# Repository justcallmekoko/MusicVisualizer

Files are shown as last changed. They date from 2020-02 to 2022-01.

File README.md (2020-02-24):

# Music Visualizer
<p align="center">
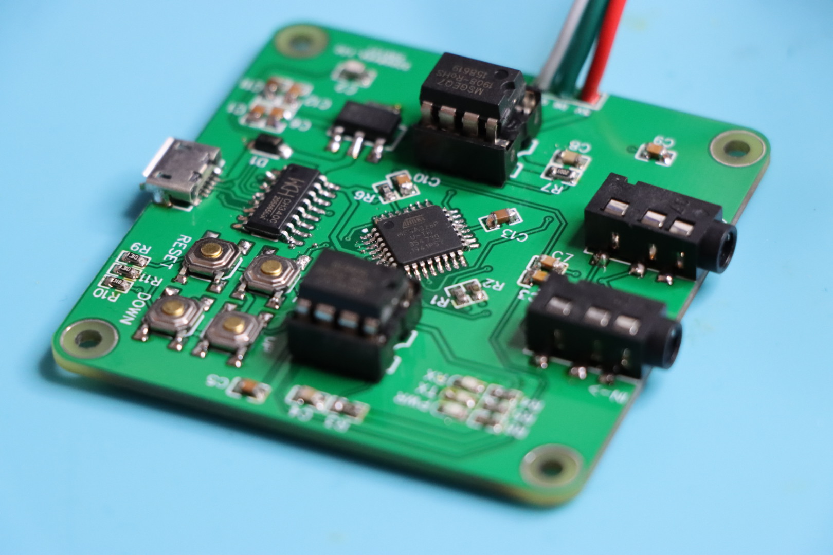
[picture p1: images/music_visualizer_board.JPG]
  
  
  <br>
  <a href="https://www.instagram.com/just.call.me.koko">Instagram</a>
  - <a href="https://www.youtube.com/channel/UCQdi3MDHHMm7u3cMkEY329Q">YouTube</a>
  <br>
  <br>
  <b>A music visualizer based on the ATMEGA328P-AU.</b>
</p>

# Table of Cadence
- [Intro](#intro)
- [Installation](#installation)
- [Usage](#usage)
  - [Cycle Button](#cycle-button)
  - [Reset Button](#reset-button)
  - [Up Button and Down Button](#up-button-and-down-button)

# Intro
*Oh god, how did it come to this?*
A while back I had published a [project](https://github.com/justcallmekoko/Arduino-FastLED-Music-Visualizer) detailing the process for creating your own music visualizer using an Arduino Uno and a [Sparkfun Spectrum Shield](https://www.sparkfun.com/products/13116). I love Sparkfun and I love Arduino, but I also love making things as simple and intuitive as possible. For these reasons, I have designed the Arduino compatible Music Visualizer based on the ATmega328p-au. It is the single board version of the original Arduino Music Visualizer from my previous project with a few other changes. Rather than using the [FastLED](https://github.com/FastLED/FastLED) library, I have employed the [Adafruit NeoPixel](https://github.com/adafruit/Adafruit_NeoPixel) library which made for some more simple code in the end. I have opted for the surface mount version of the ATmega328p for a more compact package. There is no need for any soldering or jumper wires as the connections between the spectrum analyzer, arduino, and RGB strip are already included on the board. Pretty much this project is as plug and play as possible.

# Installation
The music visualizer is meant to sit between the music source such as your phone or computer and the output speakers. For best outcome, I typically increase the volume of my music source to 100% while adjusting the volume on my speakers to the desired output volume. This will allow the visualizer to process a greater range of audio level intensities.
1. Connect a 3.5mm jack from your music source to the `IN` port of the visualizer
2. Connect another 3.5mm jack from the `OUT` port of the visualizer to the output spearkers of your choice
3. Connect a strip of [WS2812B RG LEDs](https://www.amazon.com/Aclorol-Individually-Addressable-Programmable-Non-waterproof/dp/B07BH37JGC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) no greater than 255 LEDs in length to the JST connector extending from the side of the visualizer
4. Power the visualizer using a Micro USB cable connected to a 5v power source

# Usage
Because markings on the board are different from the markings I designed on the enclosure, I will place a translation key here and I will be using the markings on the board to refer to the different buttons available to you as the user.

| Enclosure | Board |
| --- | ----- |
| C | Cycle |
| R | Reset |
| + | Up |
| - | Down  |

### Cycle Button
The Cycle Button can be used to cycle through the available patterns preprogrammed onto the visuazlier. Press the Cycle Button once to advance to the next pattern. Once the last pattern is reached, pressing the Cycle Button once more will return to the first pattern in the array. The following is a list of the current available patterns.
- Single Level: A single equalizer bar reactive to bass frequencies
- Double Level: A center mirrored equalizer bar reactive to bass frequencies
- Tracer Level: Bass frequencies of a certain intensity threshold are translated into LED tracers fired across the strip
- Double Tracer Level: Bass frequencies of a certain intensity threshold are translated into LED tracers fired from center to either end of the strip
- Active LEDs: Adjust the amount of LEDs the visualizer will use

### Reset Button
The Reset Button will hard reset the visualizer. The will cause the visualizer to reboot and load the user settings saved in EEPROM

### Up Button and Down Button
The Up Button will have different functionality depending on the current mode

#### Single Level
The Up and Down Buttons will adjust the intensity of the LED reaction for this mode

#### Double Level
Like in Single Level, the Up and Down Buttons will adjust the intensity of the LED reaction for this mode

#### Tracer and Double Tracer
The Up and Down Buttons will adjust the audio threshold that causes the LEDs to react. The lower the threshold, the low the intensity of the music required to make the LEDs react. The Up and Down Buttons in this context have a hold functionality. A single press will adjust the threshold by 1. Holding the button for longer than a half second will adjust the threshold by 1 for every processor cycle while the button is held.

#### Active LEDs
The Up and Down Buttons will adjust the amount of LEDs the visualizer will use for its effects. Because the number of LEDs in a strip cannot be determined dynamically in this configuration while strip size can change based on user discretion, you may be required to adjust the number of LEDs the visualizer "knows about". If you have a strip of 100 LEDs, you will need to adjust the number of `Active LEDs` to 100 using the Up or Down Buttons. The current number of Active LEDs is shown by lighting only the active LEDs in Red. If you fail to adjust the number of `Active LEDs` in the visualizer settings to the number of LEDs actually in your strip, the effects may not display properly on your strip i.e. overreactive or underreactive visual effects.

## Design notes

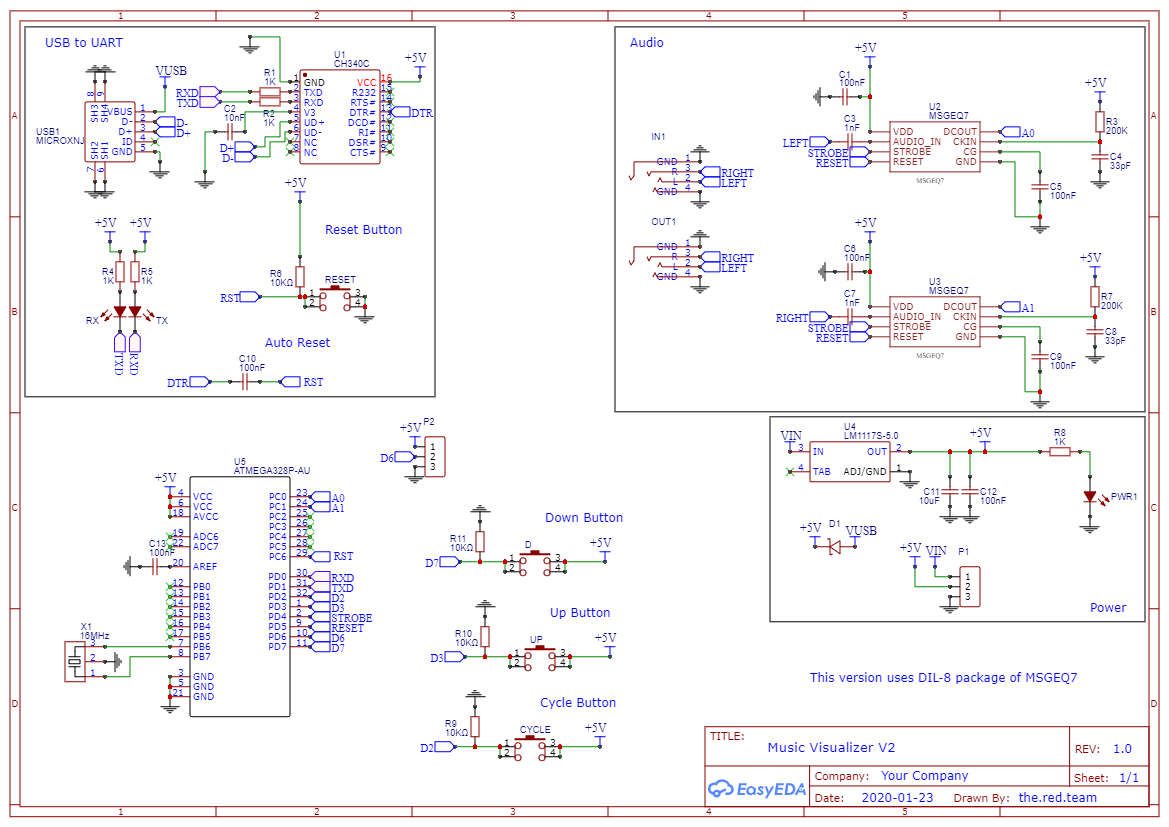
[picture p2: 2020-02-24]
schematic/Schematic_MusicVisualizerV2_MusicVisualizerV2Schematic_20200224104655.png

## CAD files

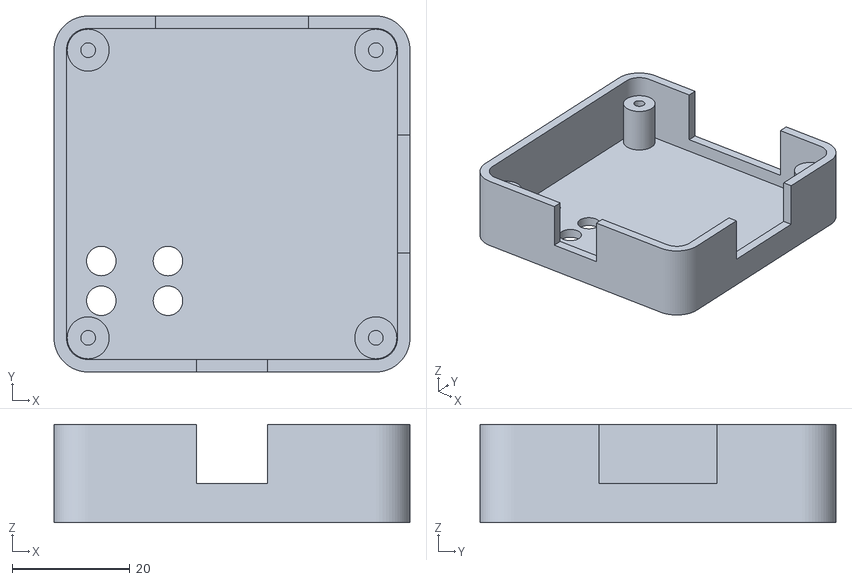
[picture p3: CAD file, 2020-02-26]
3Dfiles/Top/Visualizer_Enc_Lid_3.stl
60.4 x 60.4 x 16.6

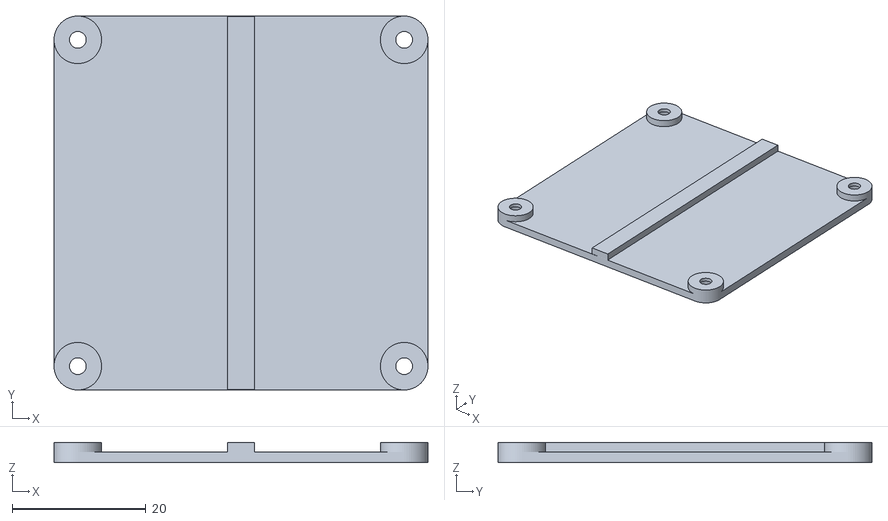
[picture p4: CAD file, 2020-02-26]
3Dfiles/Bottom/Visualizer_Enc_screw_base.stl
55.9 x 55.9 x 3.00

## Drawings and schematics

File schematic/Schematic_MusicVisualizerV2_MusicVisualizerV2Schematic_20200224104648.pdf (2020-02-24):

USB to UART | Audio

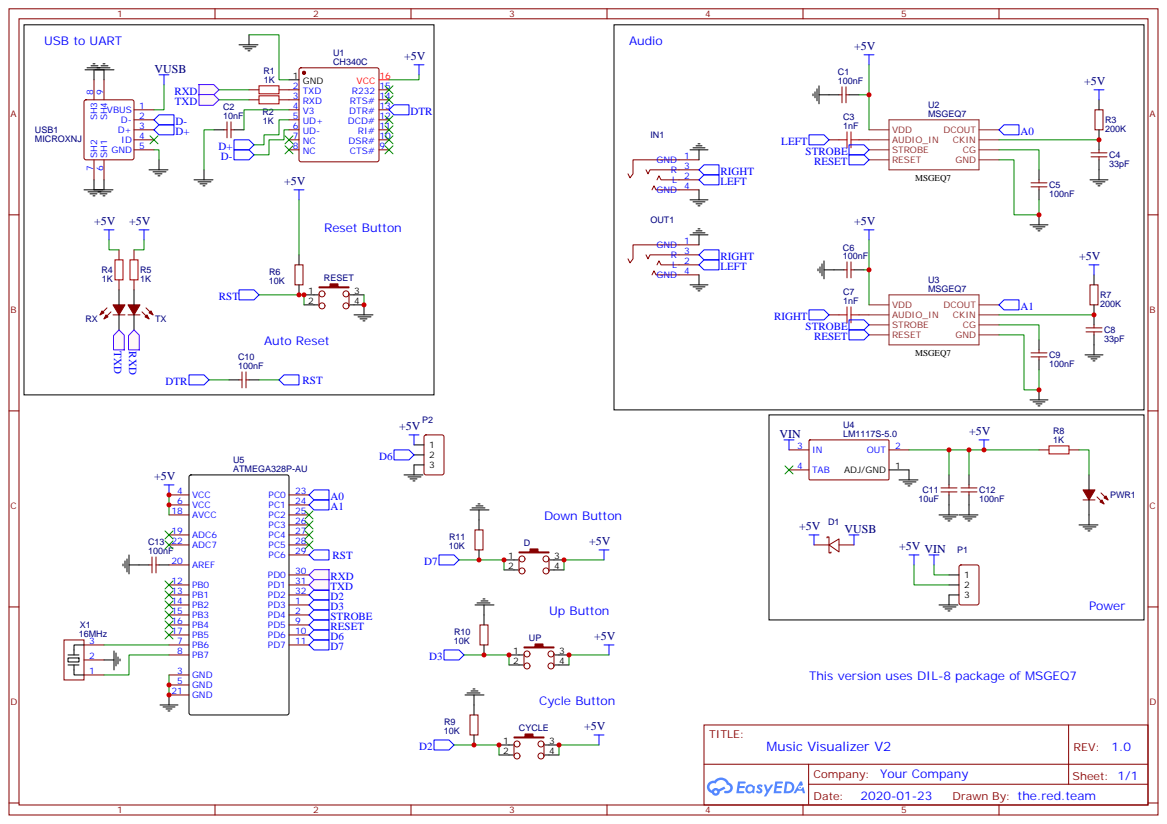
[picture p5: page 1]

DSR# 10 RI# 11 DCD# 12 DTR# 13 RTS# 14 R232 15 VCC 16

This version uses DIL-8 package of MSGEQ7

Drawn By: the.red.team

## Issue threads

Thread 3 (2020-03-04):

Test issue for project board

justcallmekoko, 2020-03-04:
Test issue for project board

Edit: Updating comment and closing issue from project board.

Closed 2020-03-04.

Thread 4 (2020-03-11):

Activate LED number setting using hold function with cycle button

justcallmekoko, 2020-03-11:
Currently the LED number setting is in the rotation of patterns. Just to keep pattern cycling neat, I want to separate the LED number setting from the pattern cycle and let the user access the setting by holding the cycle button then exit the setting by short pressing the cycle button.

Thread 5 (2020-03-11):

Display threshold adjustment on LED strip

justcallmekoko, 2020-03-11:
while adjusting threshold values, display the threshold level on the strip while adjusting and for up to 3 seconds after the up or down button is no longer pressed

Closed 2020-03-11.

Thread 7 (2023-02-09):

Convert to use Single Microphone sensor

trbbhm, 2023-02-09:
I am using this code on an Arduino board with a connected microphone sensor. My threshold is down to 100 (so as to get it responsive enough to sound picked up by the mic). When I start, my ambient sound coming from my mic is around 87. When I test the mic with music or any noise, the LEDs react as they should for a second or two, and then go full-on, and my ambient sound coming from my mic stays steady at around 127, even with no noise or sound in the room.

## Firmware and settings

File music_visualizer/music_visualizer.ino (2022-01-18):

#include <Arduino.h>
#include <stdio.h>

#include "Patterns.h"
#include "ButtonInput.h"

//Adafruit_NeoPixel strip = Adafruit_NeoPixel(NUM_LEDS, LED_PIN, NEO_GRB + NEO_KHZ800);
Adafruit_NeoPixel strip;

Patterns patternObj;

ButtonInput upButton(UP_BUTTON);
ButtonInput downButton(DOWN_BUTTON);
ButtonInput cycleButton(CYCLE_BUTTON);

uint32_t currentTime  = 0;

void setup() {
  Serial.begin(115200);

  delay(500);

  Serial.println(F("\n\nArduino Music Visualizer\n"));

  Serial.println(F("Setting audio..."));
  patternObj.setupAudio();
  
  Serial.println(F("Setting LEDs..."));
  patternObj.setupStrip();

  //patternObj.setupAudio();

  //patternObj.rainbowCycle(20);
  Serial.println("All set: " + (String)patternObj.active_leds);
}

void loop()
{
  currentTime = millis();

  patternObj.initPattern(patternObj.currentPattern, currentTime);
  
  downButton.checkPatternChange();
  upButton.checkPatternChange();
  cycleButton.checkPatternChange();
  
  //patternObj.doubleLevel();

  //patternObj.tracerLevel();
}

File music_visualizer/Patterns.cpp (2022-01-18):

#include "Patterns.h"

Patterns::Patterns()
{

}

void Patterns::saveEEPROM(long addr, int value, bool fix)
{

  if (fix) {
    int modu = value % 255; // the remainder of value after deviding by 255
    int whole_mult = (value - modu) / 255; // The number of times 255 goes into the value

    EEPROM.update(addr, modu);
    EEPROM.update(MOD_ADDR, whole_mult);

    //Serial.println("Saved remainder " + (String)modu + " to addr " + (String)addr);
    //Serial.println("Saved multiplier " + (String)whole_mult + " to addr " + (String)MOD_ADDR);
  }
  else {
    EEPROM.update(addr, value);
    //Serial.println("Saved value " + (String)value + " to addr " + (String)addr);
  }
}

void Patterns::loadActiveLEDs()
{
  //Serial.println("Loading active LEDs");
  this->active_leds = EEPROM.read(ACTIVE_LED_ADDR);
  if ((this->active_leds < 0) || (this->active_leds > NUM_LEDS)) {
    this->active_leds = NUM_LEDS;
  //  Serial.println("Loaded active_leds from default: " + (String)this->active_leds);
    this->saveEEPROM(ACTIVE_LED_ADDR, this->active_leds, true);
  }
  //else
  //  Serial.println("Loaded active_leds from EEPROM: " + (String)this->active_leds);
}

void Patterns::loadTracerThresh()
{
  // Need to calculate tracer threshold because we cannot
  // store numbers greater than 255 in EEPROM
  // tracer threshold is calculated using the int
  // stored in (MOD_ADDR * 255) + the int stored in TRACER_THRESH_ADDR
  int remainder = EEPROM.read(TRACER_THRESH_ADDR);
  int multiplier = EEPROM.read(MOD_ADDR);
  this->TRACER_THRESHOLD = (multiplier * 255) + remainder;
  if ((this->TRACER_THRESHOLD < 0) || (this->TRACER_THRESHOLD > 1023)){
    this->TRACER_THRESHOLD = DEFAULT_TRACER_THRESH;
    //Serial.println("Loaded TRACER_THRESHOLD from default: " + (String)this->TRACER_THRESHOLD);
    this->saveEEPROM(TRACER_THRESH_ADDR, this->TRACER_THRESHOLD);
  }
  //else
    //Serial.println("Loaded TRACER_THRESHOLD from EEPROM: " + (String)this->TRACER_THRESHOLD);
}

void Patterns::initPattern(int pattern, uint32_t currentTime)
{
  if (!this->checkSettingTimer(currentTime)) {
    if (pattern == SINGLE) {
      this->singleLevel();
    }
    else if (pattern == DOUBLE) {
      this->doubleLevel();
    }
    else if (pattern == TRACER) {
      this->tracerLevel();
    }
    else if (pattern == DOUBLE_TRACER) {
      this->doubleTracerLevel();
    }
    else if (pattern == PULSE) {
      this->pulsePattern();
    }
    else if (pattern == FREQ_PULSE) {
      this->freqPulsePattern();
    }
    else if (pattern == FREQ_PULSE_TAI) {
      this->freqPulsePattern();
    }
    else if (pattern == SETTING) {
      this->settingLevel();
    }
  }
  else {
    if ((pattern == TRACER) ||
        (pattern == DOUBLE_TRACER) ||
        (pattern == FREQ_PULSE) ||
        (pattern == FREQ_PULSE_TAI) ||
        (pattern == PULSE))
      this->showTracerThresh();
  }
}

void Patterns::adjustMidway(int active)
{
  this->midway = this->active_leds / 2;
  Serial.println("New midway: " + (String)this->midway);
}

void Patterns::convertSingle()
{
  if (this->left[this->freq] > this->right[this->freq])
    this->audio_input = this->left[this->freq];
  else
    this->audio_input = this->right[this->freq];

  if (this->audio_input > DOUBLE_THRESHOLD)
  {
    this->pre_react = ((long)this->active_leds * (long)this->audio_input) / 1023L; // TRANSLATE AUDIO LEVEL TO NUMBER OF LEDs

    if (this->pre_react > this->react) // ONLY ADJUST LEVEL OF LED IF LEVEL HIGHER THAN CURRENT LEVEL
      this->react = this->pre_react;
  }
}

void Patterns::convertDouble()
{
  if (this->left[this->freq] > this->right[this->freq])
    this->audio_input = this->left[this->freq];
  else
    this->audio_input = this->right[this->freq];

  if (this->audio_input > DOUBLE_THRESHOLD) {
    this->pre_react = ((long)this->midway * (long)this->audio_input) / 1023L;

    if (this->pre_react > this->react)
      this->react = this->pre_react;
  }
  
}

void Patterns::displayTracer()
{
  for (int i = 0; i < this->active_leds; i++) {
    if (this->tracerList[i] != 0)
      strip.setPixelColor(i, Wheel((i * 256 / 50 + this->k) % 256));
    else
      strip.setPixelColor(i, strip.Color(25, 0, 0));
  }

  strip.show();
}

void Patterns::settingLevel()
{
  for (int i = 0; i < NUM_LEDS; i++) {
    if (i < this->active_leds)
      strip.setPixelColor(i, strip.Color(255, 0, 0));
    else
      strip.setPixelColor(i, strip.Color(0, 0, 0));
  }

  strip.show();
}

void Patterns::showTracerThresh()
{
  long product = (long)TRACER_THRESHOLD * (long)this->active_leds;
  int thresh_react = abs(product / 1023L);
  //Serial.println("(" + (String)product + " * " + (String)this->active_leds + ") / " + (String)thresh_react + " = " + (String)thresh_react + "/" + (String)this->active_leds);
  for (int i = 0; i < NUM_LEDS; i++) {
    if (i < thresh_react)
      strip.setPixelColor(i, strip.Color(0, 0, 255));
    else
      strip.setPixelColor(i, strip.Color(0, 0, 0));
  }
  strip.show();
}

bool Patterns::checkSettingTimer(uint32_t currentTime) {

  // has not been X seconds yet
  if (currentTime - this->initTime < SETTING_TIMER)
    return true;
  else {
    return false;
  }
}

void Patterns::singleLevel()
{
  this->readMSGEQ7();
  this->convertSingle();
  this->singleRainbow();

  this->k = this->k - this->wheel_speed;
  if (this->k < 0)
    this->k = 255;

  this->decay_check++;
  if (this->decay_check > this->decay) {
    this->decay_check = 0;
    if (this->react > 0)
      this->react--;
  }
}

void Patterns::doubleLevel()
{
  this->readMSGEQ7();
  this->convertDouble();
  this->doubleRainbow();

  this->k = this->k - this->wheel_speed;
  if (this->k < 0)
    this->k = 255;

  this->decay_check++;
  if (this->decay_check > this->decay) {
    this->decay_check = 0;
    if (this->react > 0)
      this->react--;
  }
}

void Patterns::tracerLevel()
{
  this->readMSGEQ7();

  if (this->left[this->freq] > this->right[this->freq])
    this->audio_input = this->left[this->freq];
  else
    this->audio_input = this->right[this->freq];

  if (this->audio_input > TRACER_THRESHOLD) {
    this->tracerList[0] = 1;
  }
  else
    this->tracerList[0] = 0;

  this->displayTracer();
  this->shiftTracer();
}
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

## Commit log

2020-02-19 Add mirrored tracer pattern
2020-02-19 Fix blank LEDs in center of mirrored tracer
    [ButtonInput.cpp, Patterns.cpp, music_visualizer.ino]
2020-02-21 Adjust number of active LEDs
2020-02-21 Fix failed current_button_state
2020-02-24 Add schematics
2022-01-18 Fix LED Limit
